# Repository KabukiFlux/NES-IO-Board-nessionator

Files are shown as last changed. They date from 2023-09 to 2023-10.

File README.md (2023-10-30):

# NES IO Board "nessionator"

<b align="center">Nessionator, the RGB mod NES output board 
complement for Tim Worthington's NesRGB board</b>

## Table of contents

- [Why](#why)
- [Description](#description)
- [Schematics](#schematics)
- [Install](#install)
- [Pics and final result](#pics-and-final-result)

## Why?

In order to preserve the Nintendo Entertainment System some actions are required like the recapping of the components
cleaning, etc..., one way to ensure compatibility with modern TVs and improve the
image as well is by installing the Tim Worthington's NESRGB board, which interfaces between
the PPU and a CPLD to convert digital into analog signals with multiple palettes.

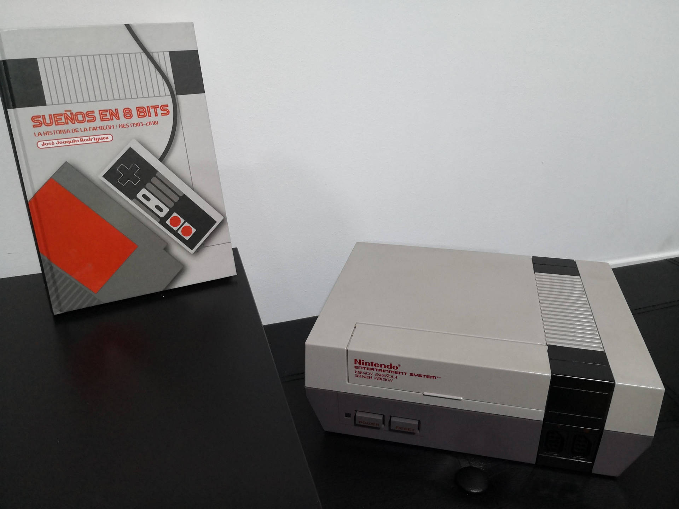
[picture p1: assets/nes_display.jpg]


## Description

This is intended to be a PCB to use with the Tim Worthington's RGB board with a standard NES from regions USA and Europe
without having to do any holes on the case.

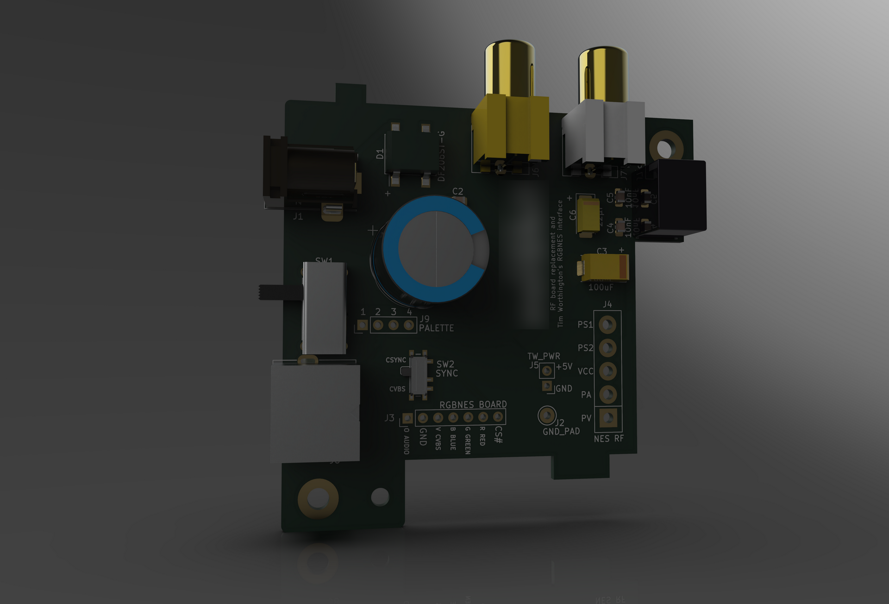
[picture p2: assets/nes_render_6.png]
NES render shot


This board uses a standard Sega Megadrive 2 RGB cable (Sega Genesis).

No cut is required on the case, so we left the outside of the console untouched.

In the BOM directory there's an interactive BOM with all the required components.

In the gerbers directory we have the gerbers to manufacture the boards.

In the KiCAD folder we can find the KiCAD project itself.

## Schematics

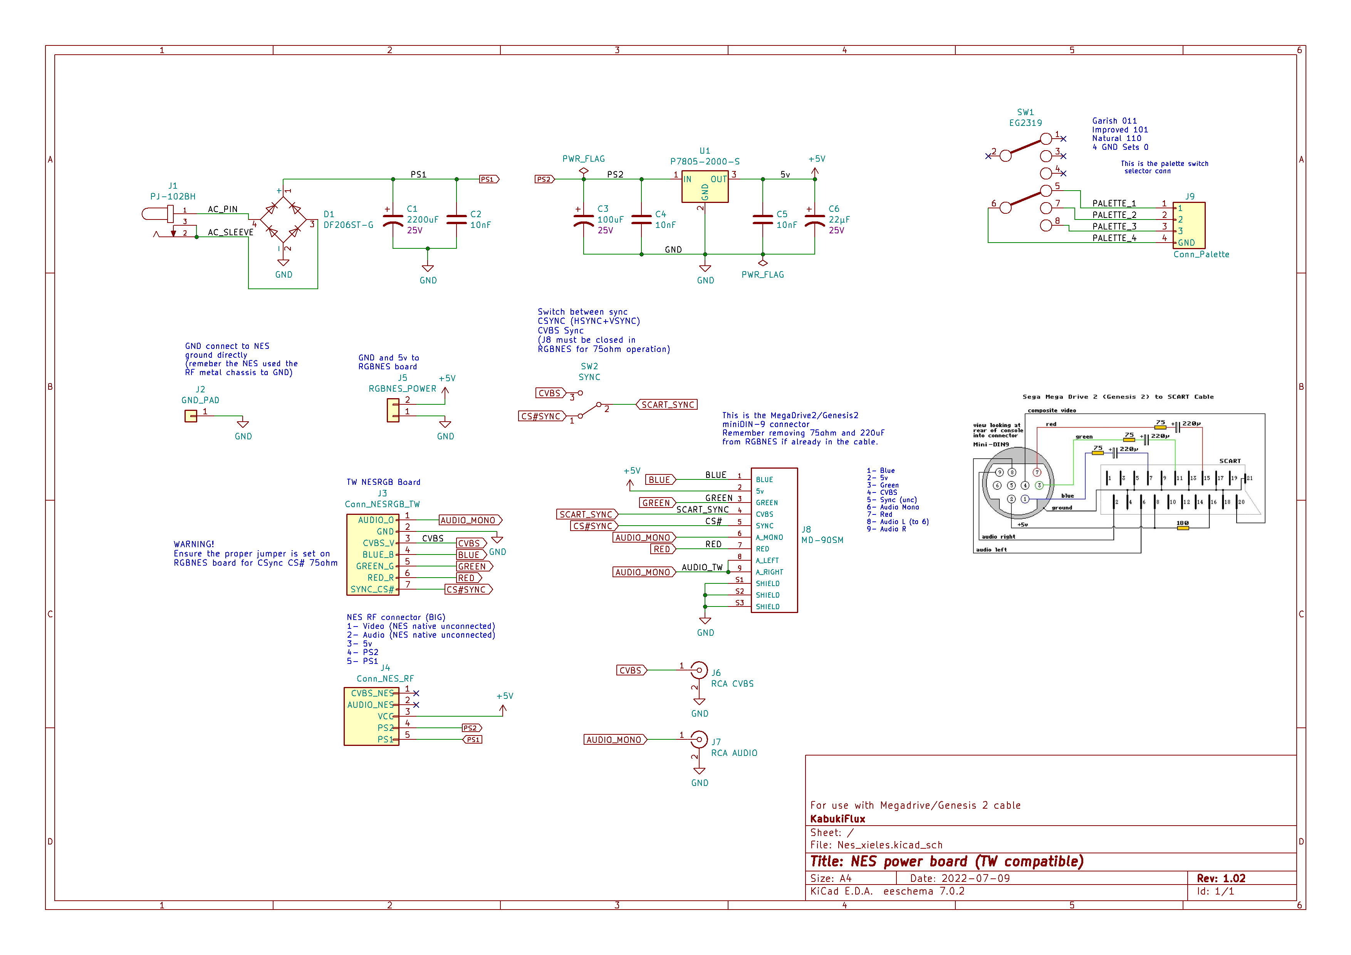
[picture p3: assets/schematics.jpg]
Schematics


You can find here as well the MD2 cable schematics inside.

## Install

1- Send to manufacture the GERBER board to JLCPCB or other PCB manufacturer.

2- Get the components required, you can see here the Bill Of Materials [BOM](bom/ibom.html)

3- Solder the components.

4- Desolder the RF from the NES but save the header pins connecting the mainboard to the RF board.

5- Follow Tim Wothington's install guide here but do not cut the case!!!: [Guide](https://etim.net.au/nesrgb/installation-nes/) 

6- Follow this soldering guide:

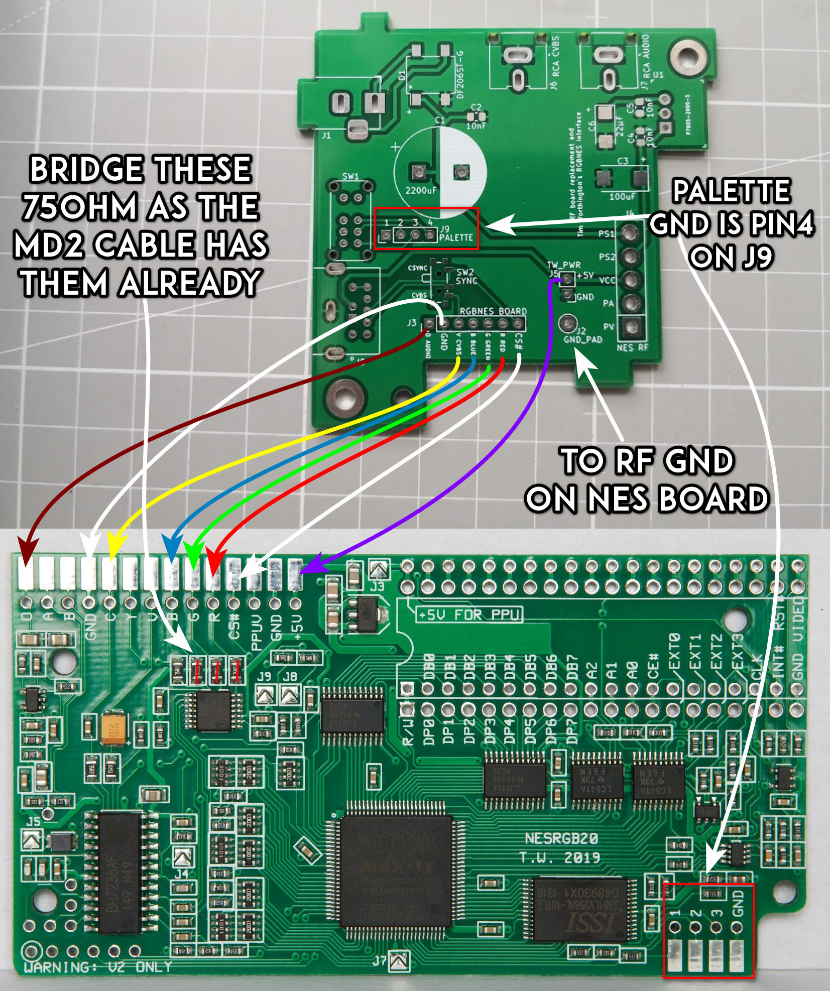
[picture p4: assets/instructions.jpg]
Soldering guide


At this stage you should have something like this:

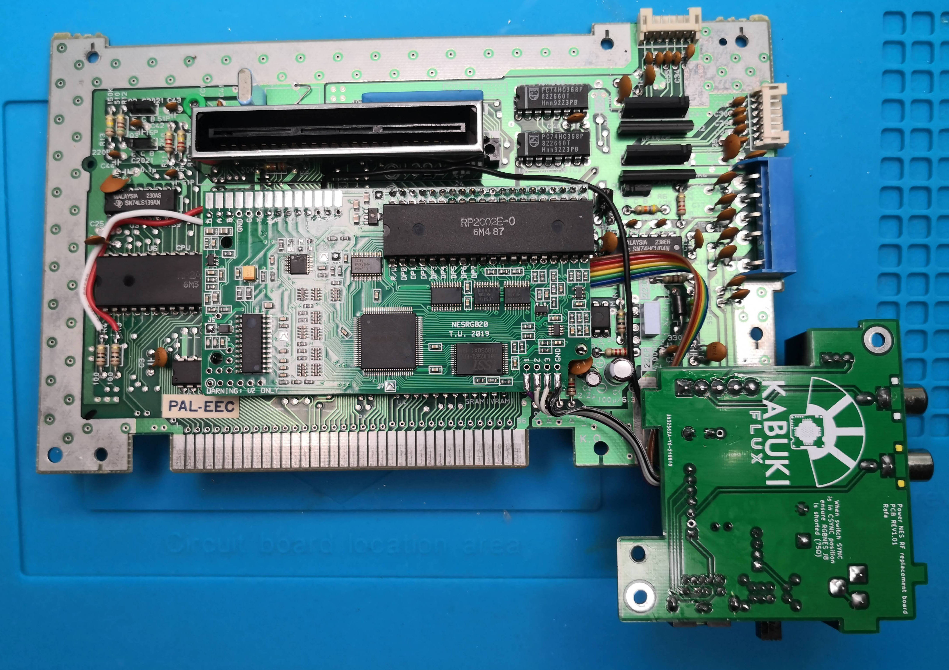
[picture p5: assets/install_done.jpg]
Install done


This is a pic with the NESRGB installed for NTSC 60Hz, check the manual for PAL.

Remember to bridge the output 75 ohm resistors as the MD2 cable already has them inside.

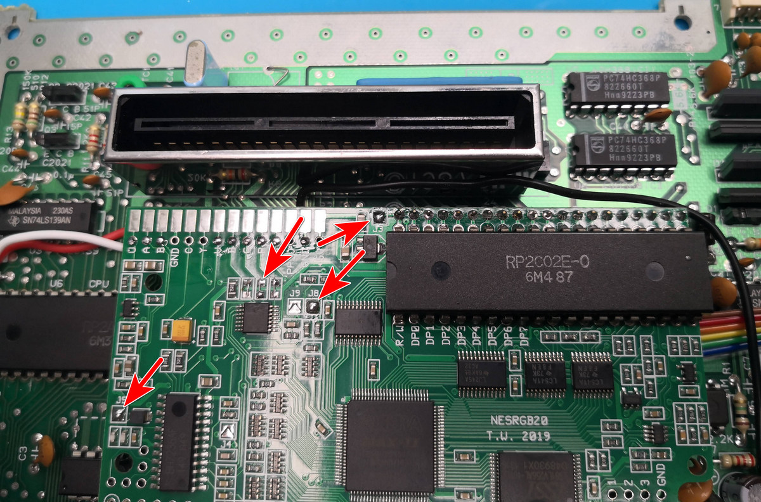
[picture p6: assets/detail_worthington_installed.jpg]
Install done etim


* Be careful with the DCDC switching supply IC

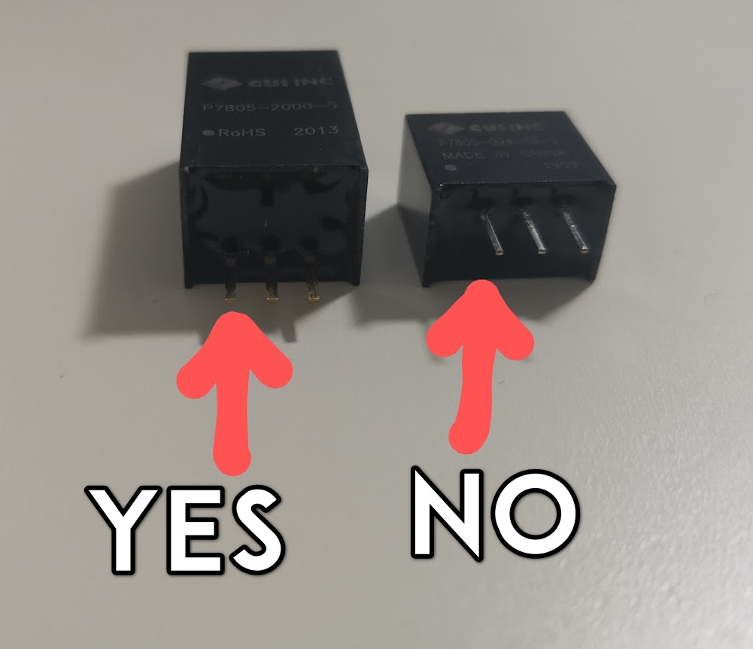
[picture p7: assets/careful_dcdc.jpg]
DCDC CUI


### Pics and final result

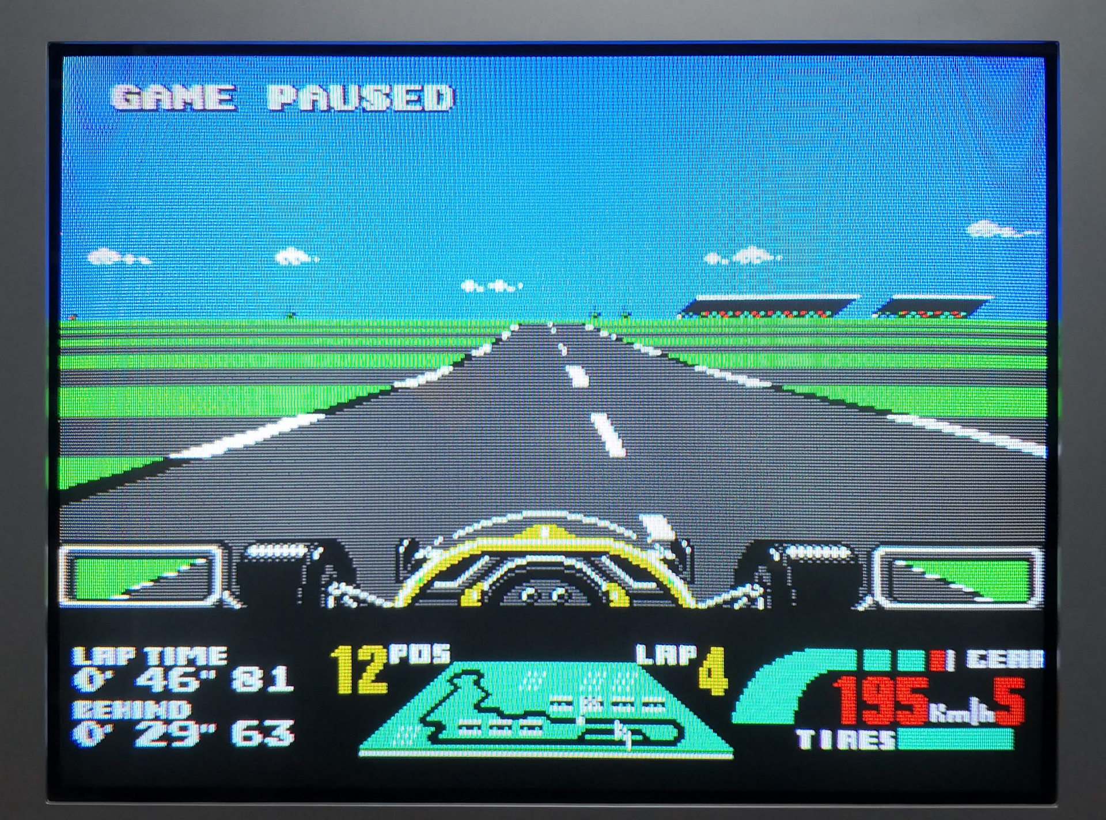
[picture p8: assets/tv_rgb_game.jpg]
TV SHOT


I know, not the best shot showing the RGB.

<br>

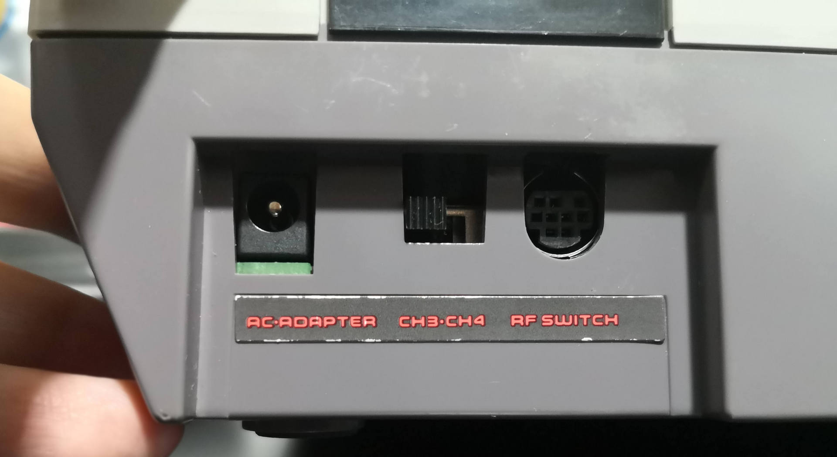
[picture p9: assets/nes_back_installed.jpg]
Back installed


<br>

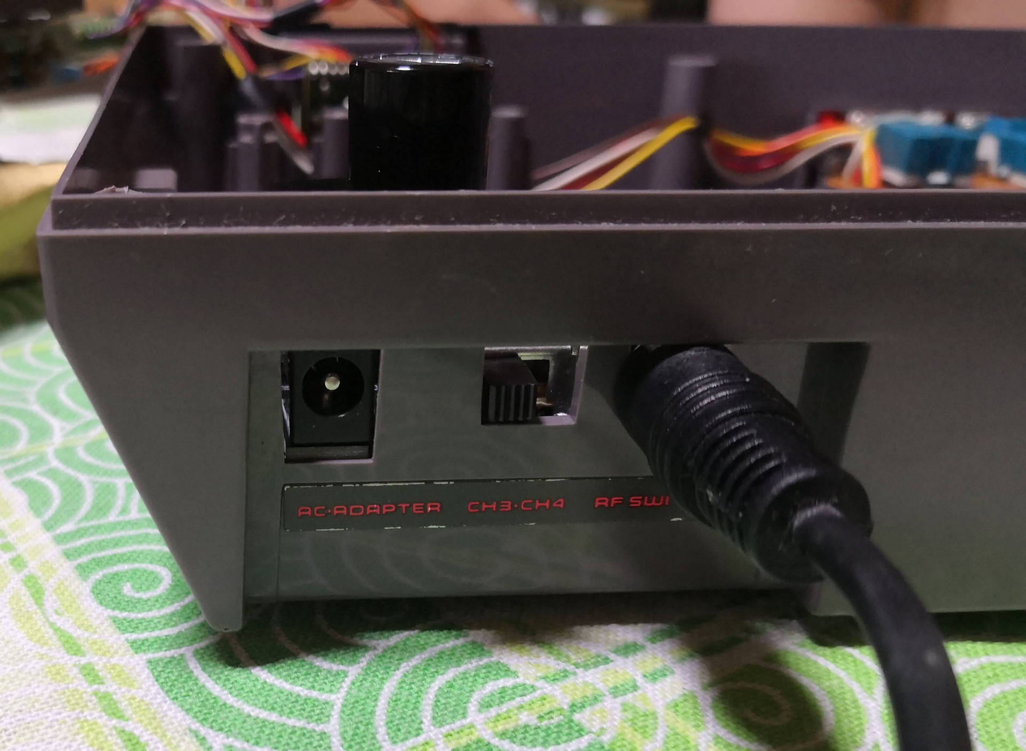
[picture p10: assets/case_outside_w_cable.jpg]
Back installed with cable


I'm not responsible
============
And yes, read below, no responsibility taken on bad use.

DISCLAIMER (See Licensing)
==========================
See LICENSE fo more information.

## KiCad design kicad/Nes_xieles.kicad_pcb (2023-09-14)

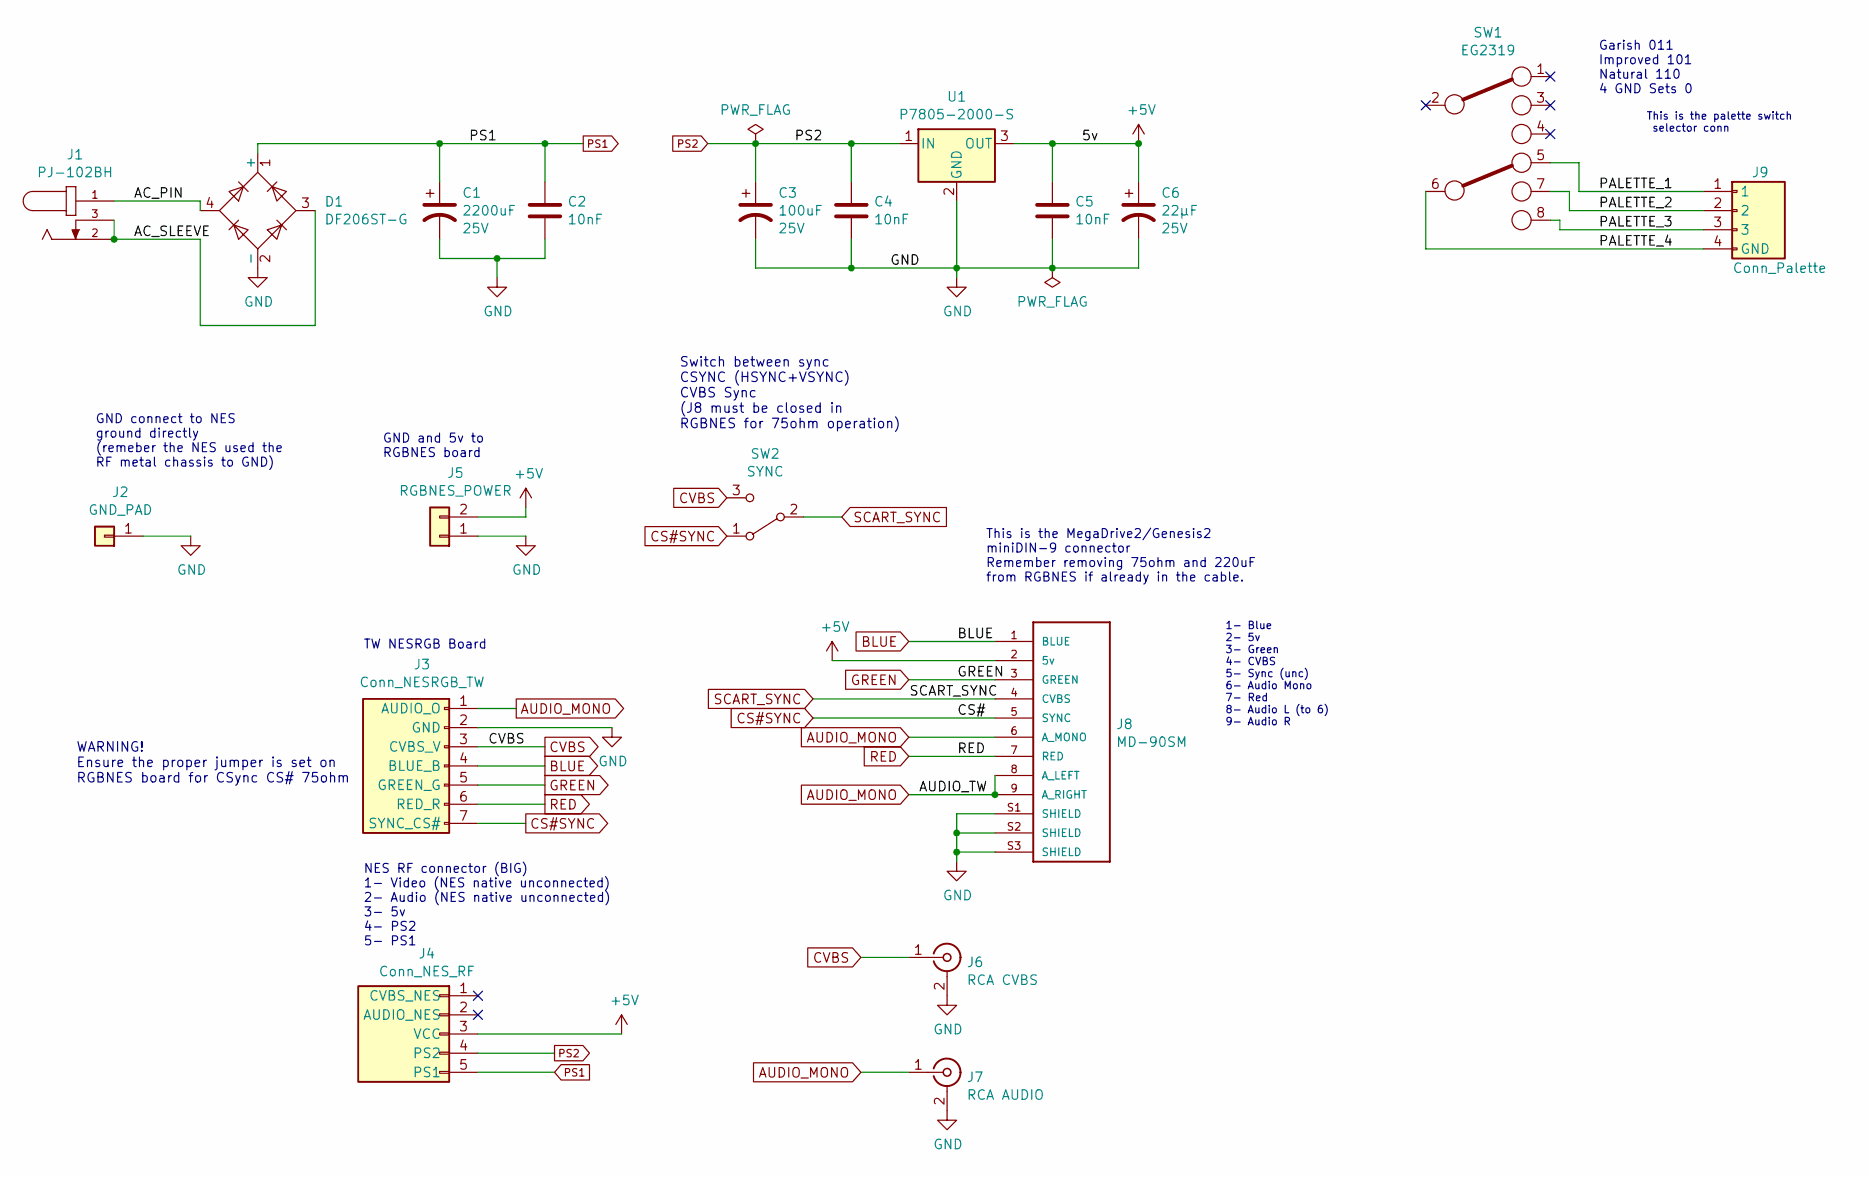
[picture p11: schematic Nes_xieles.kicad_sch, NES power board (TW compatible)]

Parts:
C1: 2200uF; CP_Radial_D16.0mm_P7.50mm; Voltage 25V; Mouser REF 647-UKL1E222KHD
C2, C4, C5: 10nF; C_0805_2012Metric_Pad1.15x1.40mm_HandSolder; Mouser REF 80-C0805X103J3G7800
C3: 100uF; CP_EIA-7343-43_Kemet-X_Pad2.25x2.55mm_HandSolder; Voltage 25V; Mouser REF 80-T495X107K25ATE150
C6: 22μF; CP_EIA-6032-28_Kemet-C_Pad2.25x2.35mm_HandSolder; Voltage 25V; Mouser REF 80-T491C226K025
D1: DF206ST-G; Diode_Bridge_Vishay_DFS; Mouser REF 750-DF206ST-G
J1: PJ-102BH; BarrelJack_NES; Mouser REF 490-PJ-102BH
J2: GND_PAD; Pin_D1.3mm_L11.0mm
J3: Conn_NESRGB_TW; PinHeader_1x07_P2.54mm_Vertical
J4: Conn_NES_RF; RF_CONN_NES
J5: RGBNES_POWER; PinHeader_1x02_P2.54mm_Vertical
J6: RCA CVBS; CUI_RCJ-043; Mouser REF 490-RCJ-043
J7: RCA AUDIO; CUI_RCJ-043; Mouser REF 490-RCJ-043
J8: MD-90SM; CUI_MD-90SM; Mouser REF 490-MD-90SM
J9: Conn_Palette; PinHeader_1x04_P2.54mm_Vertical
SW1: EG2319; Mouser REF 612-EG2319
SW2: SYNC; SW_SPDT_PCM12; Mouser REF 611-PCM12SMTR
U1: P7805-2000-S; 3-SIP_Module_V7805-500; Mouser REF 490-P7805-2000-S

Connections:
+5V: C5.1, C6.1, J4.3 (VCC), J5.2, J8.2 (5v), U1.3 (OUT)
/AC_PIN: D1.4, J1.1
/AC_SLEEVE: D1.3, J1.2, J1.3
/PALETTE_1: J9.1, SW1.5
/PALETTE_2: J9.2, SW1.7
/PALETTE_3: J9.3, SW1.8
/PALETTE_4: J9.4 (GND), SW1.6
AUDIO_MONO: J3.1 (AUDIO_O), J7.1 (In), J8.6 (A_MONO), J8.8 (A_LEFT), J8.9 (A_RIGHT)
BLUE: J3.4 (BLUE_B), J8.1 (BLUE)
CS#SYNC: J3.7 (SYNC_CS#), J8.5 (SYNC), SW2.1 (A)
CVBS: J3.3 (CVBS_V), J6.1 (In), SW2.3 (C)
GND: C1.2, C2.2, C3.2, C4.2, C5.2, C6.2, D1.2 (-), J2.1, J3.2 (GND), J5.1, J6.2 (Ext), J7.2 (Ext), J8.S1 (SHIELD), J8.S2 (SHIELD), J8.S3 (SHIELD), U1.2 (GND)
GREEN: J3.5 (GREEN_G), J8.3 (GREEN)
PS1: C1.1, C2.1, D1.1 (+), J4.5 (PS1)
PS2: C3.1, C4.1, J4.4 (PS2), U1.1 (IN)
RED: J3.6 (RED_R), J8.7 (RED)
SCART_SYNC: J8.4 (CVBS), SW2.2 (B)

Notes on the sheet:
GND connect to NES ground directly (remeber the NES used the RF metal chassis to GND)
TW NESRGB Board
1- Blue 2- 5v 3- Green 4- CVBS 5- Sync (unc) 6- Audio Mono 7- Red 8- Audio L (to 6) 9- Audio R
GND and 5v to RGBNES board
Garish 011 Improved 101 Natural 110 4 GND Sets 0
NES RF connector (BIG) 1- Video (NES native unconnected) 2- Audio (NES native unconnected) 3- 5v 4- PS2 5- PS1
This is the palette switch selector conn
This is the MegaDrive2/Genesis2 miniDIN-9 connector Remember removing 75ohm and 220uF from RGBNES if already in the cable.
WARNING! Ensure the proper jumper is set on RGBNES board for CSync CS# 75ohm
Switch between sync CSYNC (HSYNC+VSYNC) CVBS Sync (J8 must be closed in RGBNES for 75ohm operation)

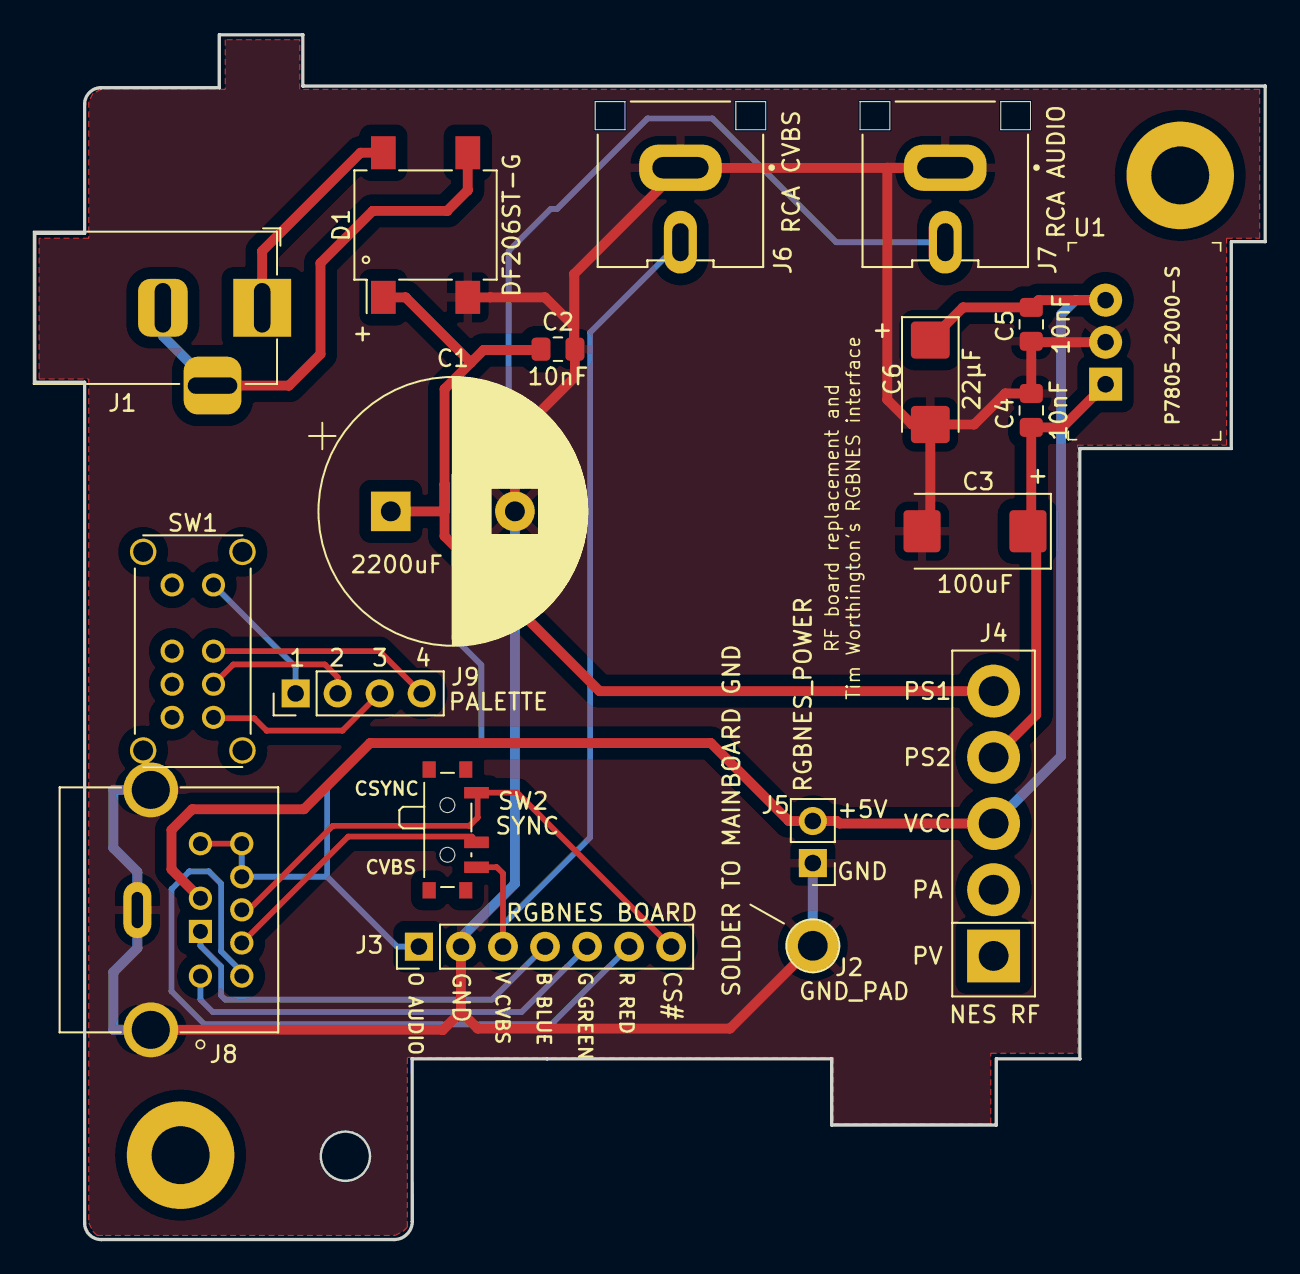
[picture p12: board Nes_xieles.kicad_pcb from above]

Board: 2 copper layers, 74.3 x 72.8 mm, 21 parts (0 on the bottom side), 17 nets.

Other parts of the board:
MH1, MH2: MountingHole_3.5mm_Pad
